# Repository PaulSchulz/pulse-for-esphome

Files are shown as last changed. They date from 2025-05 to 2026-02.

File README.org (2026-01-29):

#+TITLE: Pulse for ESPHome
#+AUTHOR: Paul Schulz

* Contents :TOC:
- [[#introduction][Introduction]]
- [[#repository][Repository]]
- [[#software-and-utilities][Software and Utilities]]
- [[#hardware-development][Hardware Development]]
  - [[#kicad][Kicad]]
  - [[#m5stamps3-microcontroller-board][M5StampS3 Microcontroller Board]]
- [[#software-development-with-esphome][Software Development with ESPHome]]
- [[#construction][Construction]]
- [[#license][License]]
- [[#resources][Resources]]
- [[#acknowledgments-and-thankyous][Acknowledgments and Thankyous]]

* Introduction
This is an [[https://esphome.io][ESPHome]] project called *pulse-for-esphome*, based on the Home Assistant Glow
which was originally created in 2011. (For more background on this project see: [[https://glow-energy.io]])

The first version of this device (hardware and firmware) has been released and
is available as a kit or completed unit. As it is also open hardware, you can
also use these files to create your own device.

A presentation on the device (with more context) called "Catch the Flash:
Measuring household power usage" was given at the [[https://2026.everythingopen.au][Everything Open 2026]]
Conference in Canberra, Australia. Presentations are available [[docs/presentations][here]].

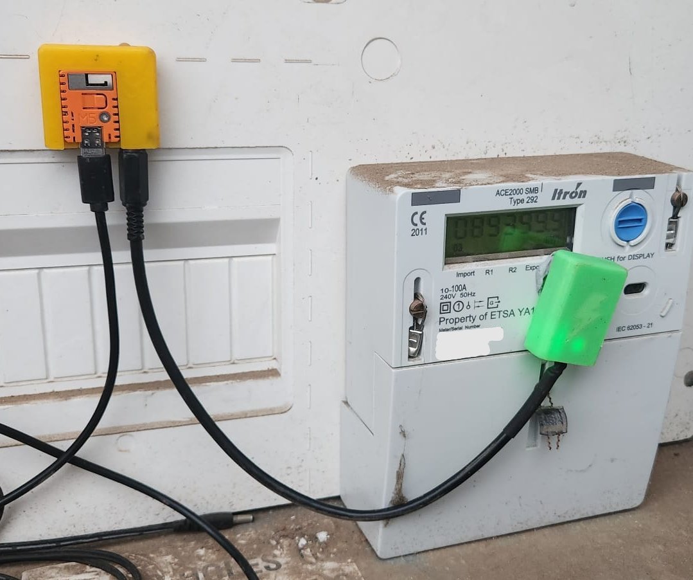
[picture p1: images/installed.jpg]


* Repository
- GitHub: https://github.com/PaulSchulz/pulse-for-esphome

* Software and Utilities

* Hardware Development
** Kicad
Kicad has been used to create a printed circuit board (PCB) which is used to
mount the microcontroller and connector for the 'flash' sensor (photodiode)
and pulse LED (for monitoring).

See: [[kicad]]

#+ATTR_HTML: :width 300px
#+ATTR_ORG: :width 300px
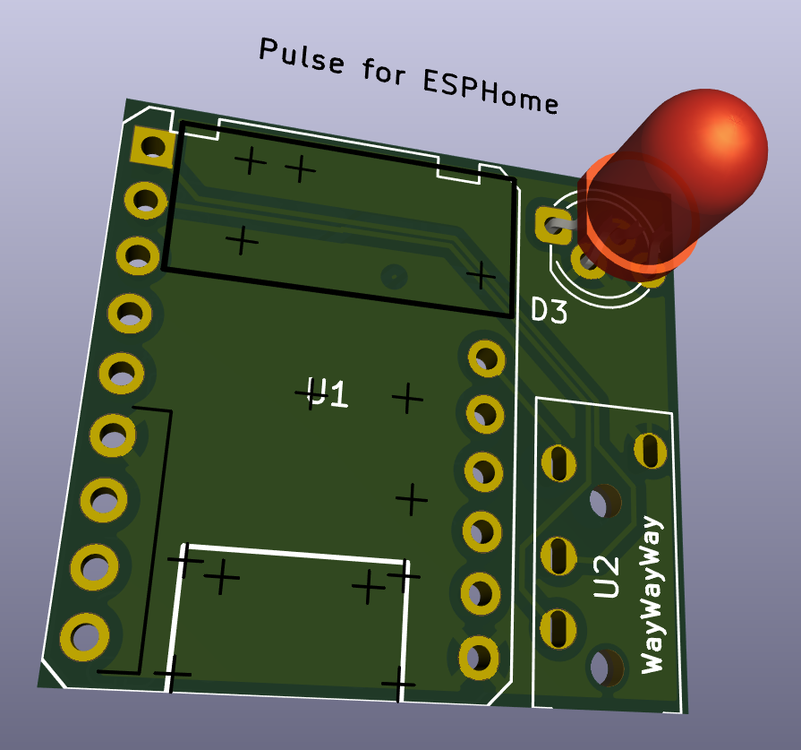
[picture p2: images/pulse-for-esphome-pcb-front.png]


#+ATTR_HTML: :width 300px
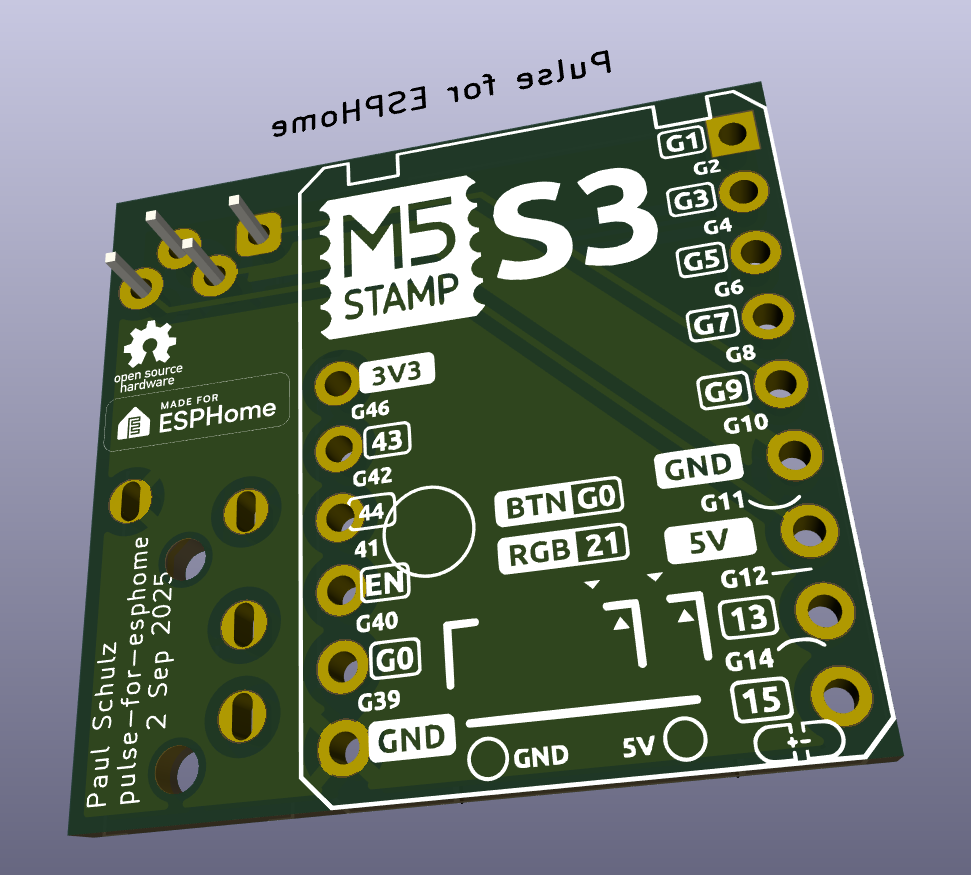
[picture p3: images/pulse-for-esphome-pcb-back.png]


** M5StampS3 Microcontroller Board

The M5StampS3 is a microcontroller board, using the ESP32-S3 microcontroller
(MCU) which is a very capable processor for running ESPHome firmware. [[https://m5stack.com/][M5Stack]]
have mounted the processor, WiFi antenna, USB-C connector, Button and Status LED in a
very handy [[https://shop.m5stack.com/products/m5stamps3a-with-1-27-header-pin][inexpensive package]].

* Software Development with ESPHome
The firmware for this device uses [[https://esphome.io/][ESPHome]]

The YAML files can be found in the [[esphome]] directory.
 
* Construction
See: [[file:docs/construction.org][BOM and Hardware Assembly Notes]]

* License
This project is licensed under the MIT License. See the [[file:LICENSE][LICENSE]] file for details.

* Resources
 TBD

* Acknowledgments and Thankyous
The project would not have been possible without the help and assistance of the
following people and groups:

- Robert Hart and the Port Adelaide Enfield Council Library - IoT Experimenters Group
- Ewan Parsons, from V3G
- Klaas Schout, and the original Home Assistant Glow project ([[https://glow-energy.io]])

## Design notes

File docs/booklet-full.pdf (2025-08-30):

# Pulse for ESPHome

### Installation Guide

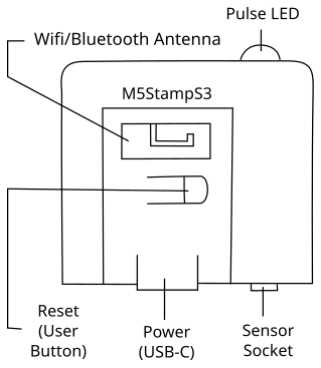
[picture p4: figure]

## Configure with

More details, documentation and code on Github https://github.com/PaulSchulz/pulse-for-esphome

### About the Pulse for ESPHome

The Pulse for ESPHome detects the pulses from your electricity meter and makes this data available via Wifi for energy monitoring in real time.

Monitoring the household electricity meter will allow you to know how much power you are consuming as you use your appliances.

Features:
* Simple to install
* No Internet, subscriptions or other services required
* Immediate access via a Web Browser * Works with Home Asssitant for long term data storage and energy management

### Installation

You will need:
- An Electricity Meter with a pulse LED
- Double sided tape
- USB-C Power Supply or Battery
- Household Wifi Network (2.4GHz)
- Web browser to view data

* Locate your household electricity meter and find the Pulse LED.
* Check the pulse rate for your electricity meter. (This is typically 1000 pulses per kWh, the default setting.)
* With double sided tape, secure the sensor (photo diode) directly over the meters pulse LED.
* Plug the sensor into the controller, and plug in USB-C for power.
* Once powered, use Improv to configure the Wifi network details (next page).

Warnings

Always use a licenced electrician when accessing or modifying household electrical wiring.

Do not lift over high voltage power lines without a network access permit.

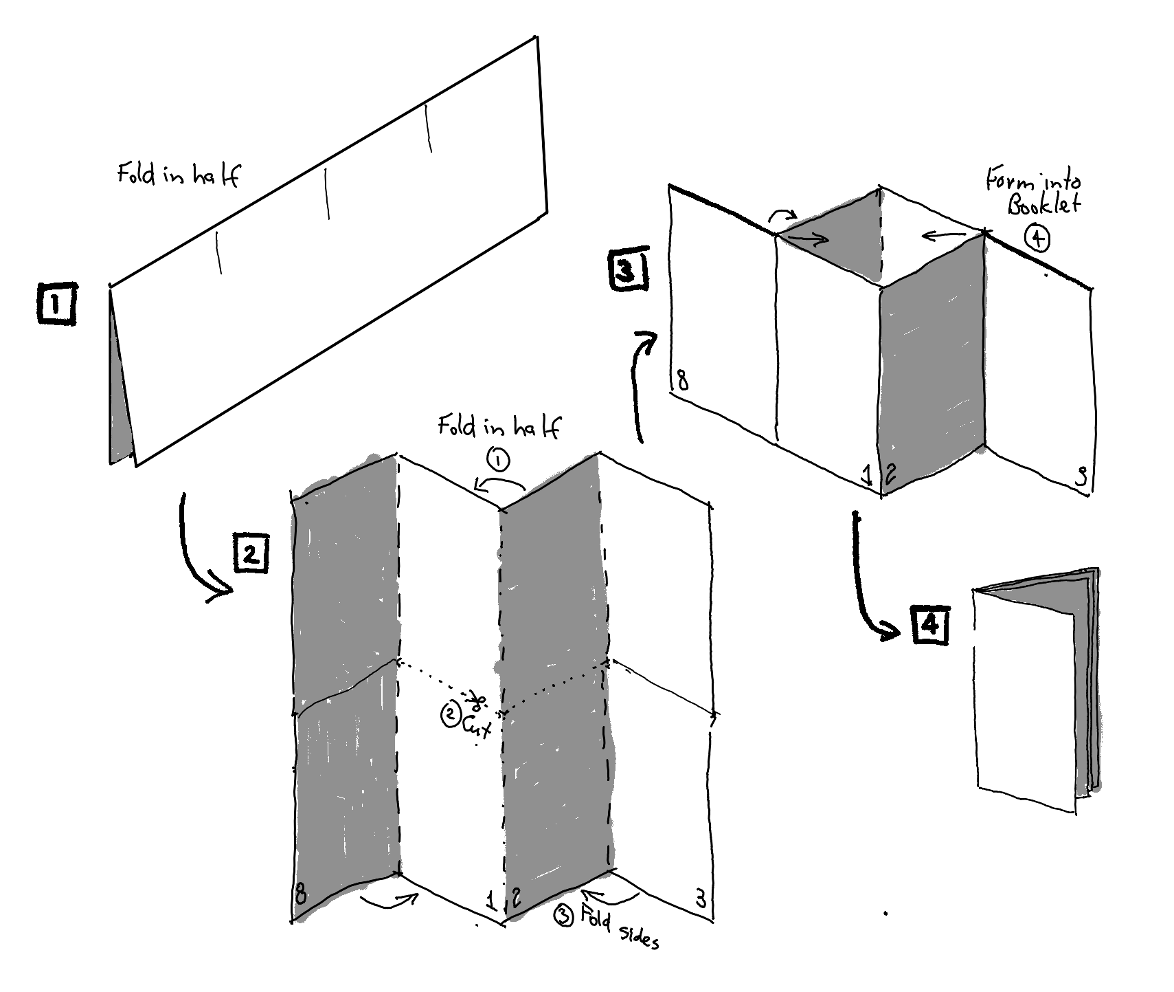
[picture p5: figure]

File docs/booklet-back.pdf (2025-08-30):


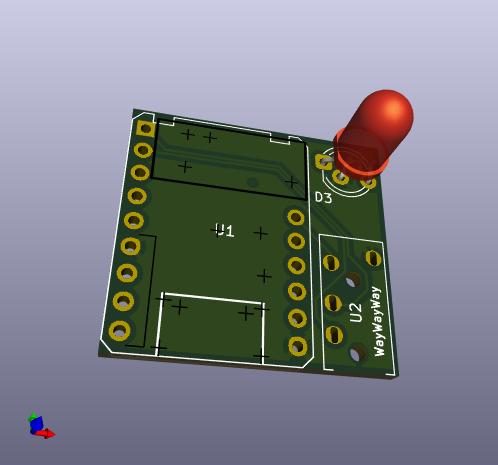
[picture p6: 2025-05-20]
images/esphome-pulse-pcb-front-20250518.jpg

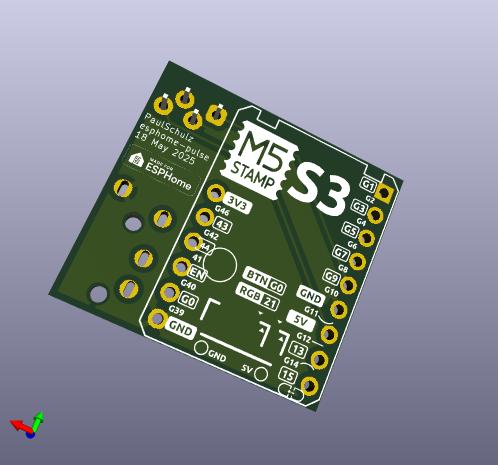
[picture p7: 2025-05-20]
images/esphome-pulse-pcb-back-20250518.jpg

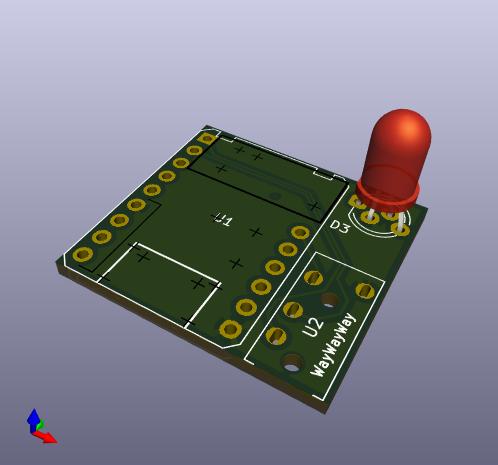
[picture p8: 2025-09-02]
kicad/pulse-for-esphome/pulse-for-esphome.jpg

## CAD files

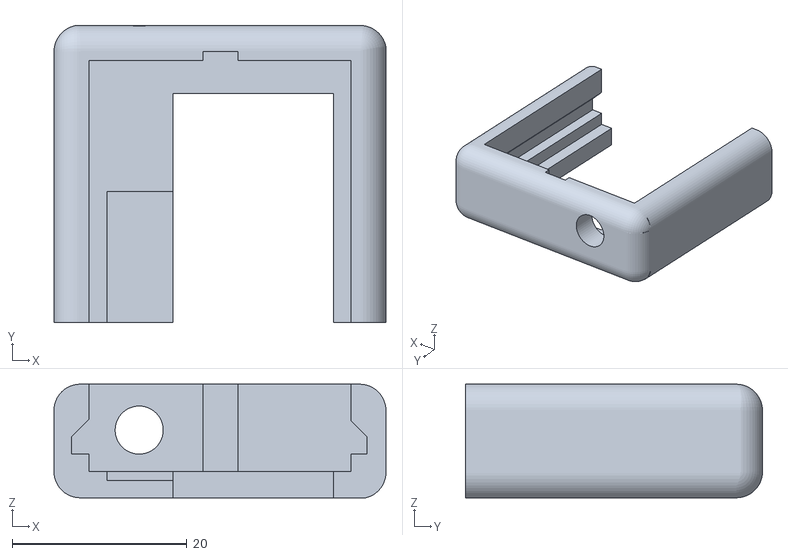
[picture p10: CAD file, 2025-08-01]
stl/esphome-pulse-topshell.stl
38.0 x 34.0 x 13.0

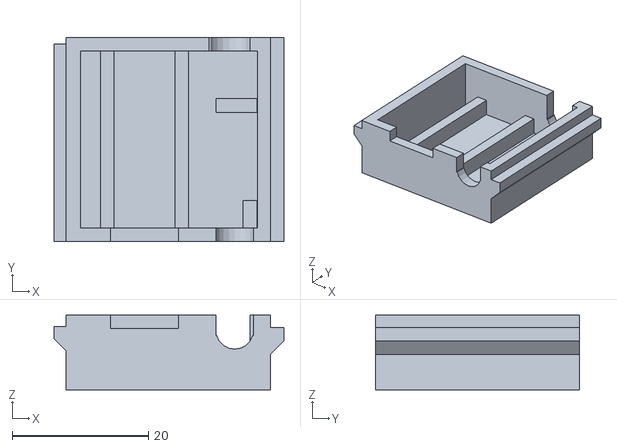
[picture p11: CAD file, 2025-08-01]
stl/esphome-pulse-backshell.stl
33.8 x 30.0 x 11.0

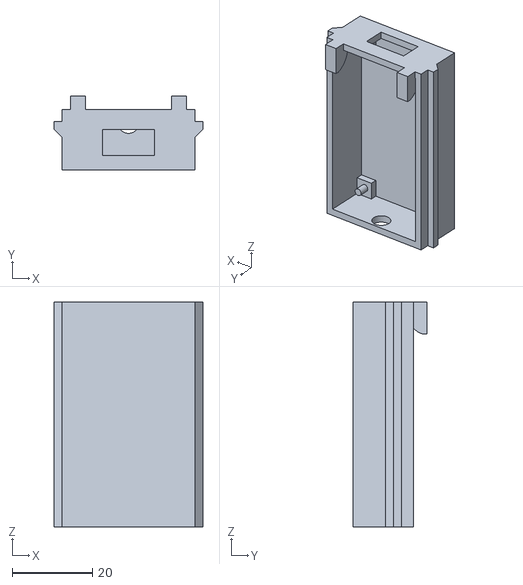
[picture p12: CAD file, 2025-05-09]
stl/ESP32_bottom_side_v1.stl
37.0 x 18.3 x 56.0

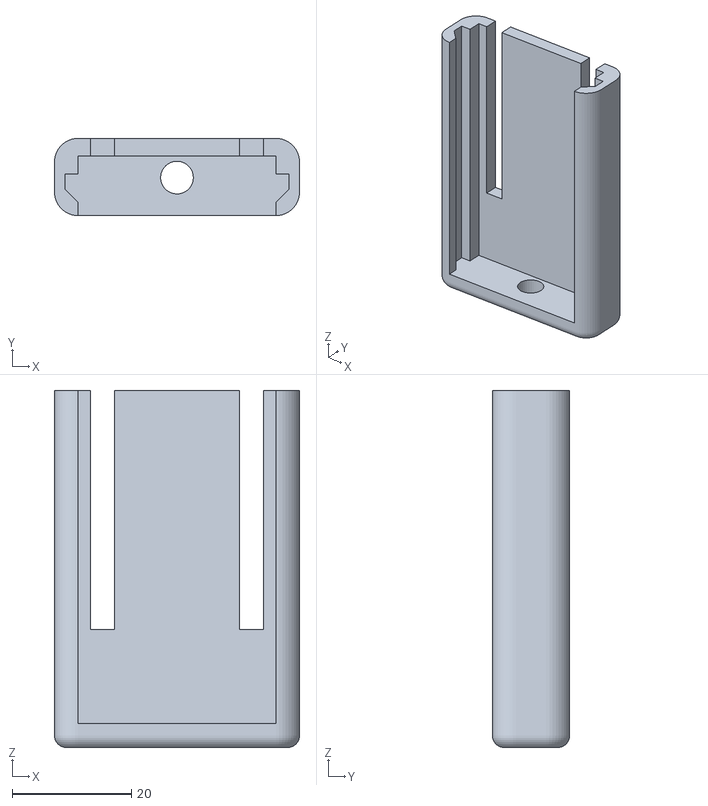
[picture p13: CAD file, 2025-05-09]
stl/ESP32_top_side_v1.stl
41.2 x 13.0 x 60.0

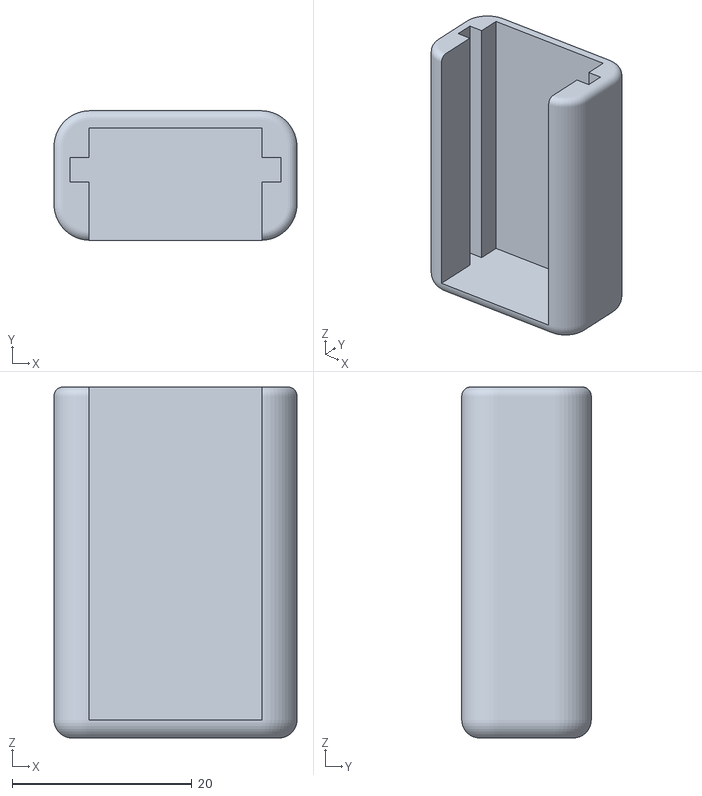
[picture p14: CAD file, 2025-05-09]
stl/Sensor_top_side_v1.stl
27.0 x 14.4 x 39.0

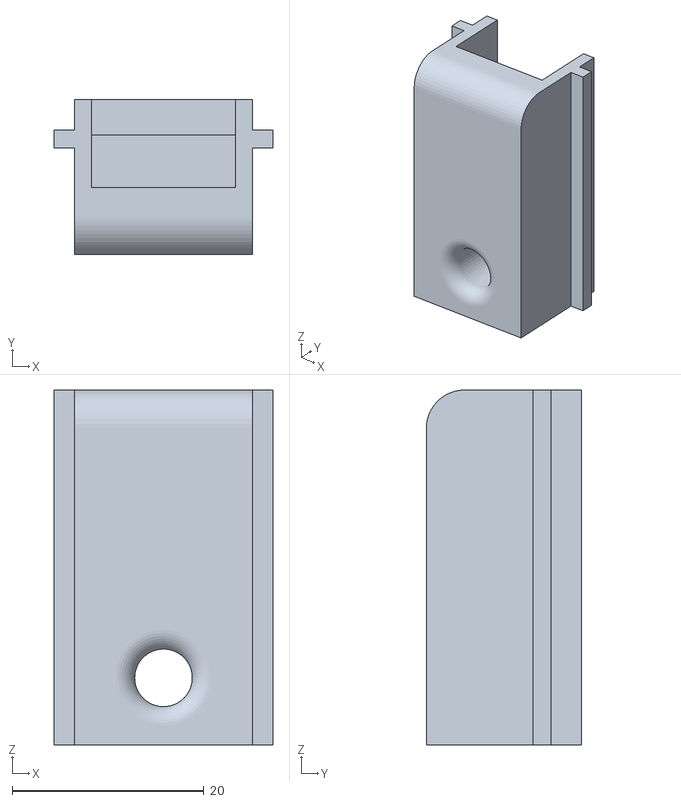
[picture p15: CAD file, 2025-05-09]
stl/Sensor_bottom_side_v1.stl
22.8 x 16.2 x 37.0

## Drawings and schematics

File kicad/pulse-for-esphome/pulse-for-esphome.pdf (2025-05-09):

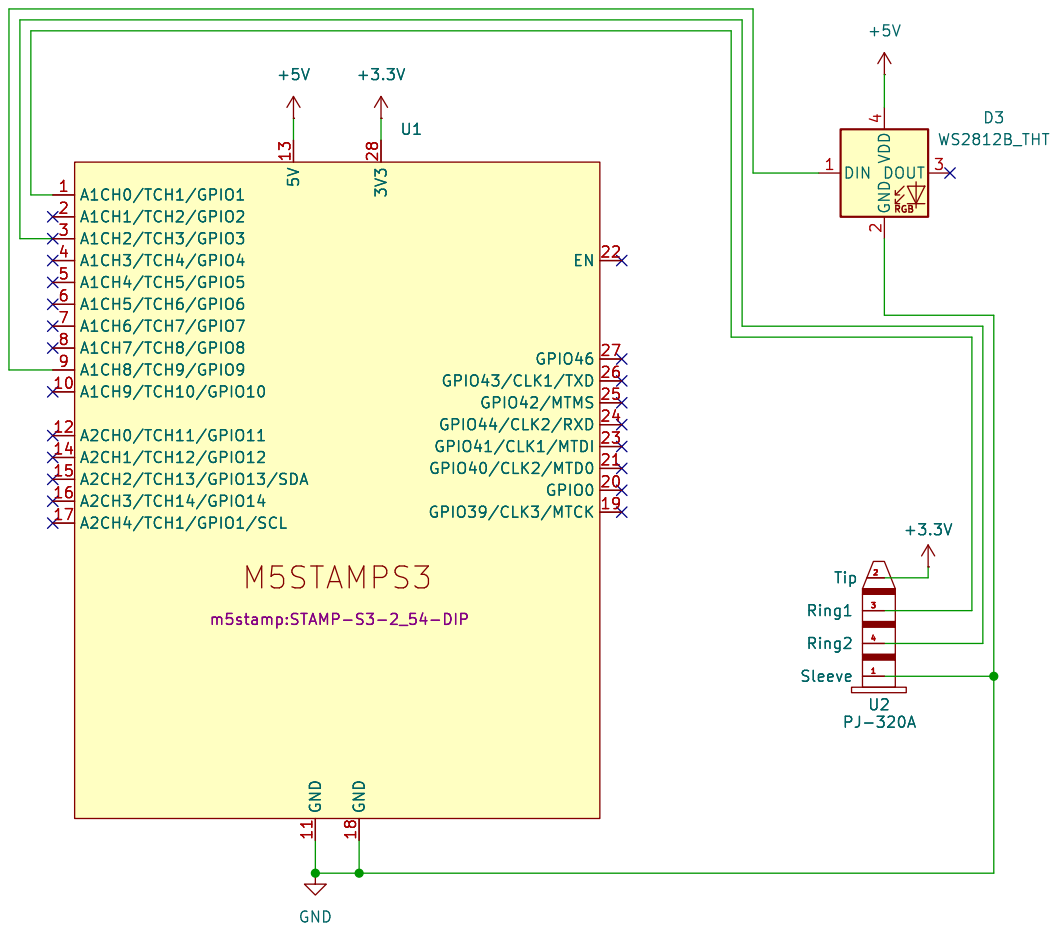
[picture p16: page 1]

File: esphome-pulse.kicad_sch Sheet: / GND

Id: 1/1 Title: ESPHome Pulse

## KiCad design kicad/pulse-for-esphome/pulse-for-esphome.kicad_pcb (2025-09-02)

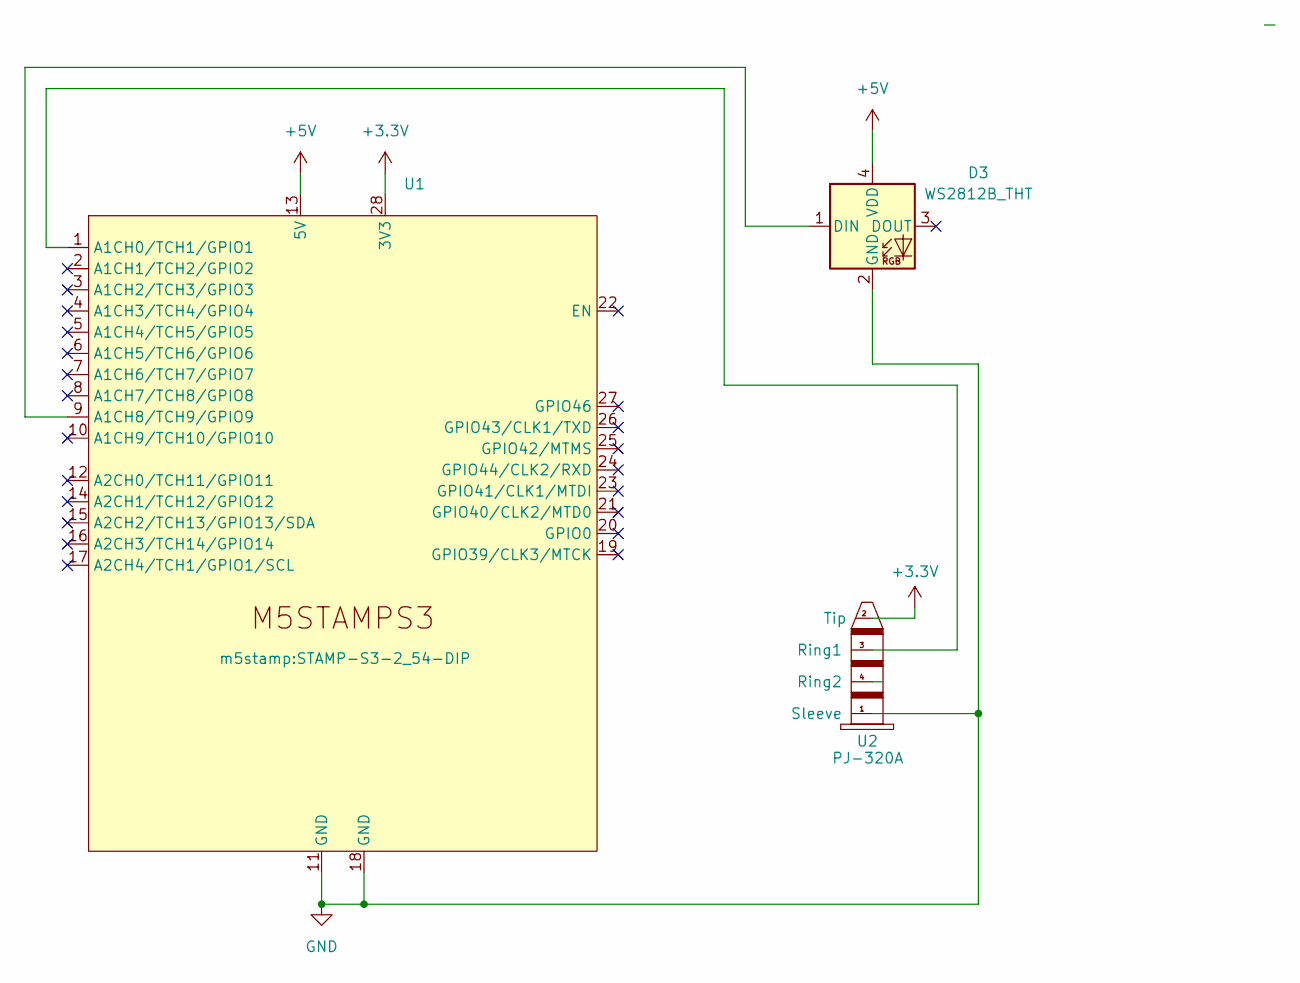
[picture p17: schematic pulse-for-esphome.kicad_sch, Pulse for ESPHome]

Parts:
D3: WS2812B_THT; LED_D5.0mm-4_RGB_Staggered_Pins
U1: STAMP-S3-2_54-DIP
U2: PJ-320A

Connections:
+3.3V: U1.28 (3V3), U2.2 (Tip)
+5V: D3.4 (VDD), U1.13 (5V)
GND: D3.2 (GND), U1.11 (GND), U1.18 (GND), U2.1 (Sleeve)
unnamed: D3.1 (DIN), U1.9 (A1CH8/TCH9/GPIO9)
unnamed: U1.1 (A1CH0/TCH1/GPIO1), U2.3 (Ring1)

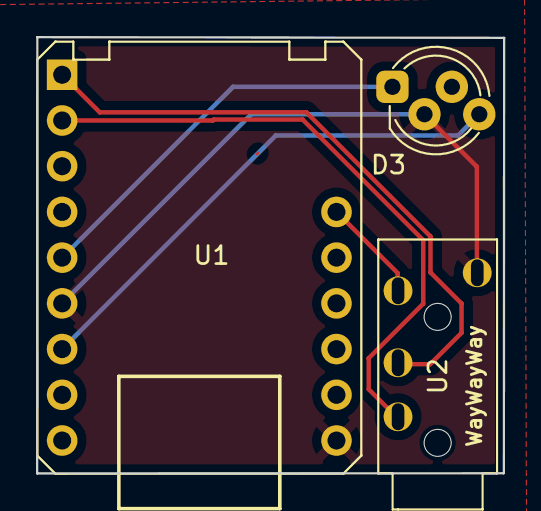
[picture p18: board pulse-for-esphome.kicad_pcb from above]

Board: 2 copper layers, 25.9 x 24.2 mm, 3 parts (0 on the bottom side), 5 nets.

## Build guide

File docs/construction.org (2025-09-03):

#+TITLE: Hardware Assembly

* Bill of Materials
** Controller Assembly
- M5Stamp-S3 with 2.54mm header pins
  See: https://shop.m5stack.com/products/m5stamps3-with-2-54-header-pin
  Price: US$7.50
  
- ESPHome-Pulse PCB
  
- Barrel Socket - 4 connector
  
- RGB LED, WS2812 (default color order - RGB)
  Pin order: 5V, Data-Out, GND, Data-In

- Enclosure - 3D printed shell
  - [[file:../stl/esphome-pulse-topshell.stl][Topshell]]
  - [[file:../stl/esphome-pulse-backshell.stl][Backshell]]
  
** Sensor Assembly
- Photodiode Sensor
  Amazon: https://www.amazon.com.au/Photodiode-Module-Brightness-Detection-Photoelectric/dp/B09LVHQ1K5
  Price: 5pcs for $6.71

  #+ATTR_HTML: :width 300px
  #+ATTR_ORG: :width 300px
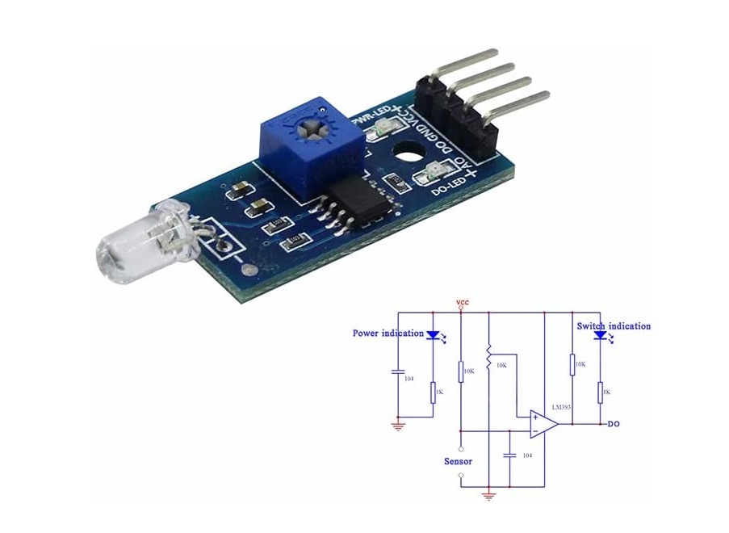
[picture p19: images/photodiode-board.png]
  

- 4 core barrel plug with lead, pre-assembled
  3.5mm Audio Cable Connector 4 Pole Male Plug, 30cm total length (+/- 1cm).
  Aliexpress: https://www.aliexpress.com/item/1005007456025757.html
  Price: AU$2.12 
  
- Heat Shrink
  - 1x 3mm x 15mm - cable insulator
  - 4x 2mm x 10mm - individual conductor insulator 

- Enclosure - 3D printed shell
  - [[file:../stl/Sensor_top_side_v1.stl][Top Side]]
  - [[file:../stl/Sensor_bottom_side_v1.stl][Bottom Side]]
  
* Controller Unit Assembly

** Soldering

** Case

** Assembly

** Programming

* Sensor Unit Assembly
The photodiode board can be purchased pre-assembled from Amazon, as well a
pre-assembled plug and tail, which can be purchased from AliExpress. The
required tasks are to solder the plug and tail to the board, with heat-shrink,
and 3D print and assemble the enclosure.

** Attach the lead to the photodiode sensor board
- Insert heat-shrink onto end of  
- Solder leads
  Red(VCC,Tip),Black(GND,Base sleeve),White(DO, Ring 1), Green(A0, Ring 2)
- Apply heat to the heat shrink

** Assembly
- Put assembly into enclosure base and slide top to secure.

* Testing

- Connect sensor to controller
  
- Connect USB Power supply
  
- Connect to Wifi using Wiki Improv, Bluetooth BLE or USB Serial
  Webpage: https://www.improv-wifi.com
  
- Connect to webpage
  - Confirm that RGB LEDs can be switched and changed color
    
- Test pulse sensor by putting sensor in front of top led, and press 'Test
  Pulse' on webpage interface. Pulse LED should start continiously pulsing,
  until sensor moved away.

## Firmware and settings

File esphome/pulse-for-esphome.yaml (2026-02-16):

---
# Pulse for ESPHome
#
# Read your electricity meter by means of the pulse LED on your
# meter, useful if you do not have a serial port (P1).
#
# Original Project: Home Assistant Glow
#  
#  © Klaas Schoute
# Adaptated as "Pulse for ESPHome"
#  Paul Schulz

substitutions:
  project_name: pulse-for-esphome
  device_name: pulse-for-esphome
  friendly_name: Pulse for ESPHome
  project_version: "1.0.7"
  device_description: |
    Measure your energy consumption with the pulse LED on your electricity meter.
  
  # Define the GPIO pins
  pulse_pin:  GPIO1
  pulse2_pin: GPIO3
  pulse3_pin: GPIO5
  pulse4_pin: GPIO7
  pulse_led:  GPIO9
  status_led: GPIO21

esphome:
  name: pulse-for-esphome
  name_add_mac_suffix: true
  project:
    name: mawsonlakesorg.${project_name}
    version: ${project_version}
    
  on_boot:
    priority: -10
    then:
      - text_sensor.template.publish:
          id: firmware_version
          state: !lambda 'return {"${project_version}"};'
  
esp32:
  # board: m5stack-stamps3
  board: esp32-s3-devkitc-1
  framework:
    type: arduino

dashboard_import:
  package_import_url: github://PaulSchulz/pulse-for-esphome/esphome/pulse-for-esphome.yaml@main
  import_full_config: false

logger:

#packages:
#  pulse_meter:  !include components/pulse_meter.yaml

wifi:
improv_serial:
esp32_improv:
  authorizer: none
api:
  reboot_timeout: 0min
  services:
    - service: reset_total_energy
      then:
        - button.press:
            id: button_reset_total

ota:
  - platform: esphome
  - platform: web_server

web_server:
  port: 80
  version: 3
  local: true

#mqtt:
#  broker:   !secret mqtt_broker
#  username: !secret mqtt_username
#  password: !secret mqtt_password
###################################################################################
script:
  - id: pulse
    then:
      - light.addressable_set:
          id: pulse_led
          range_from: 0
          range_to: 1
          red: 100%
          green: 100%
          blue: 100%
      - delay: 50ms
      - light.addressable_set:
          id: pulse_led
          range_from: 0
          range_to: 1
          red: 0%
          green: 0%
          blue: 0%
###################################################################################
number:
  # Set the pulse rate of the LED on your meter
  - platform: template
    id: select_pulse_rate
    name: "Pulse rate - imp per kWh"
    optimistic: true
    mode: box
    min_value: 100
    max_value: 10000
    step: 100
    restore_value: yes
    initial_value: 1000

  # Reset total energy to given value
  - platform: template
    id: select_reset_total
    name: 'Reset Value - Total Energy kWh'
    entity_category: config
    optimistic: true
    mode: box
    min_value: 0
    max_value: 1000000
    step: 1
    initial_value: 0

###################################################################################
binary_sensor:
  - platform: gpio
    pin:
      number: GPIO0
      mode: INPUT_PULLUP
      inverted: true
    name: "User Button"
    id: user_button
    disabled_by_default: false
    on_multi_click:
      - timing:
          - ON for at least 4s
        then:
          - light.addressable_set:
              id: status_led
              range_from: 0
              range_to: 1
              red: 100%
              green: 100%
              blue: 100%
          - delay: 50ms
          - light.addressable_set:
              id: status_led
              range_from: 0
              range_to: 1
              red: 0%
              green: 0%
              blue: 0%
          - button.press: reset

###################################################################################
light:
  - platform: fastled_clockless
    name: "Status LED"
    id: status_led
    pin: ${status_led}
    chipset: WS2812
    rgb_order: GRB
    num_leds: 1

  - platform: fastled_clockless
    name: "Pulse LED"
    id: pulse_led
    pin: ${pulse_led}
    chipset: WS2812
    rgb_order: RGB
    num_leds: 1

###################################################################################
button:
  - platform: template
    name: "Test Pulse"
    on_press:
      -  script.execute: pulse
    # Restarted the ESP
  - platform: restart
    name: "Restart"

  - platform: factory_reset
    name: Restart with Factory Default Settings
    id: reset

  # Reset the total energy entity
  - platform: template
    id: button_reset_total
    name: "Reset Total Energy"
    on_press:
      - pulse_meter.set_total_pulses:
          id: power_consumption
          value: !lambda "return id(select_reset_total).state * id(select_pulse_rate).state;"
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

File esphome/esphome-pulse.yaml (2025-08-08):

---
# ESPHome Pulse
#
# Read your electricity meter by means of the pulse LED on your
# meter, useful if you do not have a serial port (P1).
# Original: © Klaas Schoute - Home Assistant Glow
# Adaptation: Paul Schulz

substitutions:
  device_name: esphome-pulse
  friendly_name: ESPHome Pulse
  project_version: "1.0.1"
  device_description: |
    Measure your energy consumption with the pulse LED on your smart meter.
  
  # Define the GPIO pins
  pulse_pin:  GPIO1
  pulse2_pin: GPIO3
  pulse3_pin: GPIO5
  pulse4_pin: GPIO7
  pulse_led:  GPIO9
  status_led: GPIO21

esphome:
  name: esphome-pulse
  name_add_mac_suffix: true

  on_boot:
    priority: -10
    then:
      - text_sensor.template.publish:
          id: pulse_version
          state: !lambda 'return {"${project_version}"};'
  
esp32:
  # board: m5stack-stamps3
  board: esp32-s3-devkitc-1
  framework:
    type: arduino

logger:

packages:
  # logger:     !include common/logger.yaml
  wifi:       !include common/wifi-improv.yaml
  ota:        !include common/ota.yaml
  api:        !include common/api.yaml
  web_server: !include common/web_server.yaml

  pulse_meter:  !include components/pulse_meter.yaml

  #remote_package:
  #  url: https://github.com/klaasnicolaas/home-assistant-glow/
  #  ref: "4.2.3"
  #  files:
    #  - components/basis.yaml
    #  - components/updates.yaml
    #  - components/status_led.yaml
    #  - components/pulse_meter.yaml

###################################################################################
script:
  - id: pulse
    then:
      - light.addressable_set:
          id: pulse_led
          range_from: 0
          range_to: 1
          red: 100%
          green: 100%
          blue: 100%
      - delay: 50ms
      - light.addressable_set:
          id: pulse_led
          range_from: 0
          range_to: 1
          red: 0%
          green: 0%
          blue: 0%
###################################################################################
binary_sensor:
  - platform: gpio
    pin:
      number: GPIO0
      mode: INPUT_PULLUP
      inverted: true
    name: "User Button"
    id: user_button
    disabled_by_default: false
    on_multi_click:
      - timing:
          - ON for at least 4s
        then:
          - light.addressable_set:
              id: status_led
              range_from: 0
              range_to: 1
              red: 100%
              green: 100%
              blue: 100%
          - delay: 50ms
          - light.addressable_set:
              id: status_led
              range_from: 0
              range_to: 1
              red: 0%
              green: 0%
              blue: 0%
          - button.press: reset

###################################################################################
light:
  - platform: esp32_rmt_led_strip
    rgb_order: GRB
    pin: ${status_led}
    num_leds: 1
    rmt_channel: 0
    chipset: ws2812
    name: "Status LED"
    id: status_led

  - platform: esp32_rmt_led_strip
    rgb_order: RGB
    pin: ${pulse_led}
    num_leds: 1
    rmt_channel: 1
    chipset: ws2812
    name: "Pulse LED"
    id: pulse_led
    color_correct: [85%,85%,85%]

button:
  - platform: template
    name: "Test Pulse"
    on_press:
      -  script.execute: pulse
    # Restarted the ESP
  - platform: restart
    name: "Restart - Pulse"

  - platform: factory_reset
    name: Restart with Factory Default Settings
    id: reset

text_sensor:
  - platform: template
    name: "ESPHome Pulse - Installed version"
    id: pulse_version
    icon: "mdi:label-outline"
    entity_category: diagnostic
    lambda: |-
      return {"${project_version}"};
    update_interval: 6h

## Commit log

2025-04-22 Initial commit of PCB design
    [esphome-pulse.kicad_pcb, esphome-pulse.kicad_sch]
2025-04-26 Sent to production
    [esphome-pulse.kicad_pcb, esphome-pulse.kicad_sch]
2025-05-09 Add second version of PCB with smaller barrel jack
    [ESP32_bottom_side_v1.stl, ESP32_top_side_v1.stl, Sensor_bottom_side_v1.stl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]
2025-05-14 Remove older files and add README
    [esphome-pulse-v2.kicad_pcb, esphome-pulse.kicad_pcb]
2025-05-20 Update PCB and add images to README
    [esphome-pulse.kicad_pcb]
2025-07-21 kicad: Close board outline cut
    This error was raised in the Engineering Design Rule checks.
    [esphome-pulse.kicad_pcb]
2025-08-01 docs: Add and fix some missing documentation
    [esphome-pulse-backshell.stl, esphome-pulse-topshell.stl]
2025-08-01 esphome: Commit firmware changes
    - Use improv serial and bluetooth to provision wifi details.
    - Add 'factory reset' if user button held down for 4 seconds
    (with LED flash to confirm)
    [esphome-pulse.yaml]
2025-08-01 images: Rename PCB images
2025-08-01 README: Adds front and backl images of PCB from Kicad
2025-08-08 firmware: 1.0.1 - Adds missing configuration for pulse sensor
    While working with the original Home Assistant Glow, it was discovered that
    additional configuration was needed to stop double triggering when registering a
    pulse.
    This had not been added to the firmware for esphome-pulse.
    [esphome-pulse.yaml]
2025-08-30 doc: Remove references to 'secrets' file in README
    The 'secrets.yaml' file is no longer needed, or desired, for ESPHome devices,
    and so has been removed. Notes on how the 'secrets' file was previously
    configured in this project has been removed from the README file.
2025-09-02 hardware: Migrate project name to pulse-for esphome
    [pulse-for-esphome.kicad_pcb, pulse-for-esphome.kicad_sch]
2025-09-02 firmware: Change LED component to fastled_clockless
    This change was done as the 'esp32_rmt_led_strip' was having problems with the
    newer version of ESPHome (and newer libraries). FastLED works with ESPHome
    versions to 2025.9.0-dev (including 2025.8.2)
    Also:
    - Moved the configs from 'common' into the main script (and removed the common dir.)
    - Added OTA updates from the webpage.
    - Simplified some of the sensor/device names.
    [pulse-for-esphome.yaml]
2025-10-14 utils: Initial comit pf utility to produce custom device file
2025-10-14 pulse-fetch-data: Update log file format
    Added format version header.
    Format version: powershare 1.0.0
    - datetime_utc - including seconds
    - datetime_local - including seconds
    - total_watt_hours_in
    - total_watt_hours_out - currently 0, included for future bi-directional
    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
2026-02-09 firmware: Add 'for ESPHome' settings
    - Added project name and version, as required by 'for ESPHome' settings.
    - Added commented out mqtt section for reference.
    - Added set on reset timeout on API, to support sensors which are note connected
    to Home Assistant API (otherwise device will reboot if not accessed via API).
    [pulse-for-esphome.yaml]
2026-02-11 firmware: 1.0.6 Add Wifi signal sensor
2026-02-16 firmware: 1.0.7 Adds internal temperature sensor
2026-03-27 firmware: pulse2-for-esphome 1.0.6 - Adds uptime sensor
